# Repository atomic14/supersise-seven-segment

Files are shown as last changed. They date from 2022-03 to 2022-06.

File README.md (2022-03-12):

# Supersize Seven Segment Display

The code, schematics and PCB layout are offered here without any support. It's fun project but it's also a learning experience.

You can watch a full video of the completed project here: https://youtu.be/l18NYKRv0g0

Demo Video (https://www.youtube.com/watch?v=l18NYKRv0g0)

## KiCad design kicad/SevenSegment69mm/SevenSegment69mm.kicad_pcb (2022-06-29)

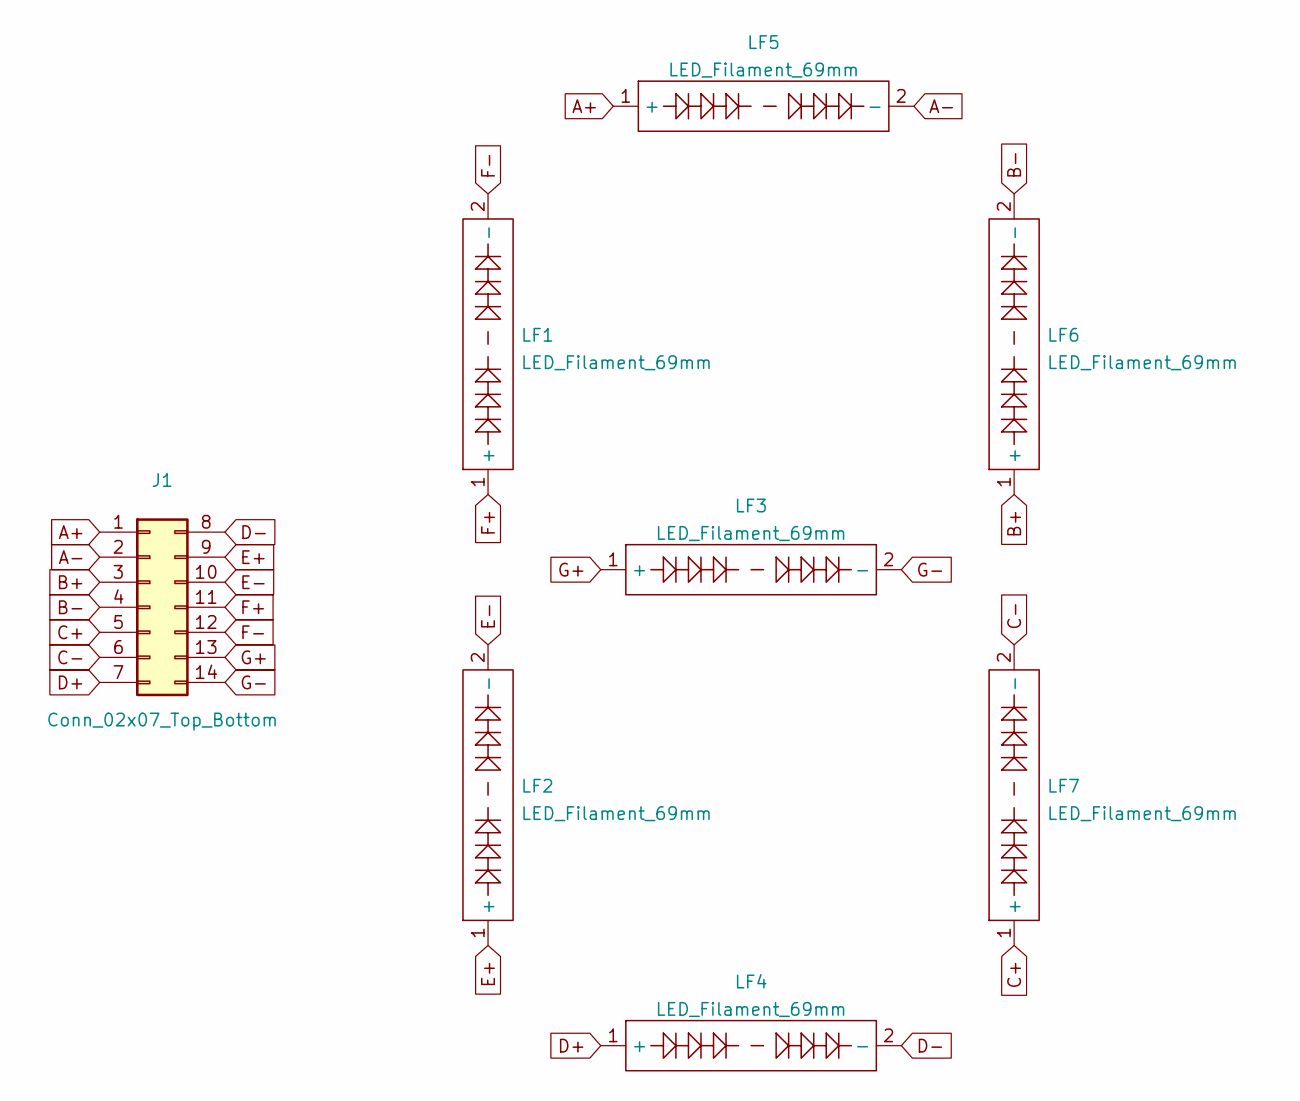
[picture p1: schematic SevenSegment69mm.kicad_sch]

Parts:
J1: Conn_02x07_Top_Bottom; PinHeader_2x07_P2.54mm_Horizontal
LF1, LF2, LF3, LF4, LF5, LF6, LF7: LED_Filament_69mm

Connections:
A+: J1.1, LF5.1 (+)
A-: J1.2, LF5.2 (-)
B+: J1.3, LF6.1 (+)
B-: J1.4, LF6.2 (-)
C+: J1.5, LF7.1 (+)
C-: J1.6, LF7.2 (-)
D+: J1.7, LF4.1 (+)
D-: J1.8, LF4.2 (-)
E+: J1.9, LF2.1 (+)
E-: J1.10, LF2.2 (-)
F+: J1.11, LF1.1 (+)
F-: J1.12, LF1.2 (-)
G+: J1.13, LF3.1 (+)
G-: J1.14, LF3.2 (-)

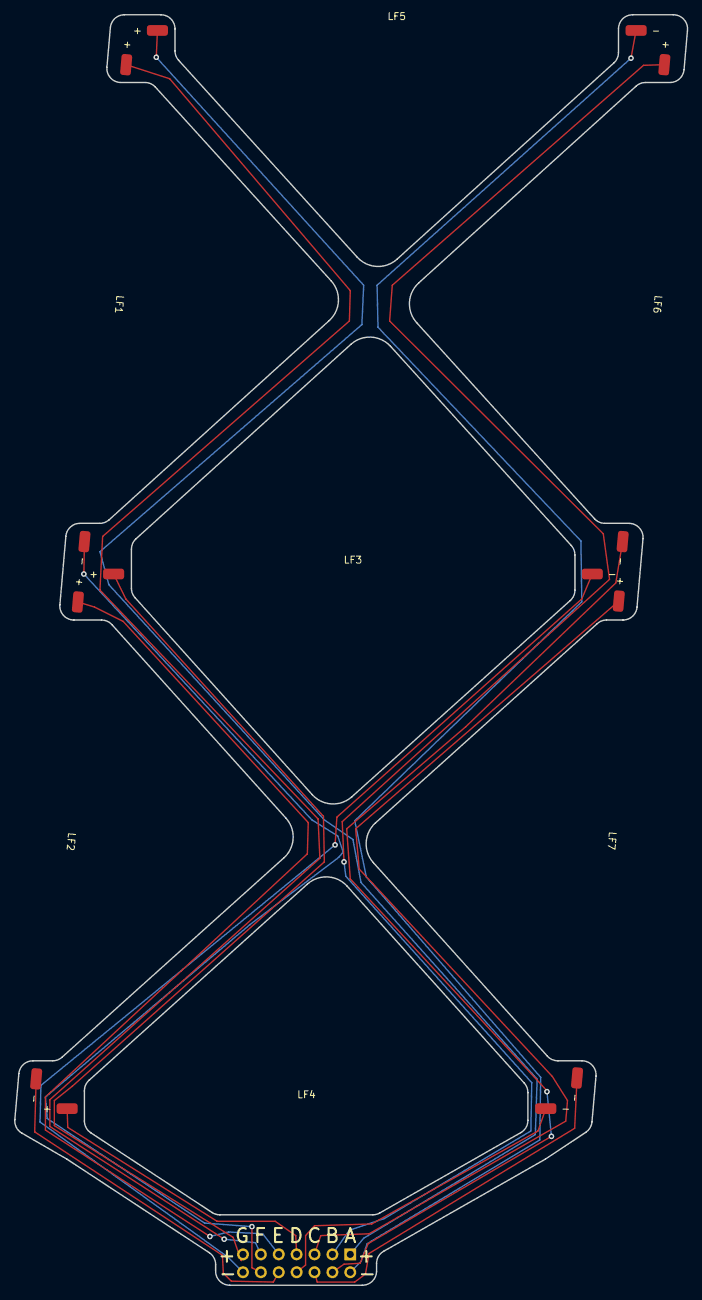
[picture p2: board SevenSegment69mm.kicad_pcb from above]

Board: 2 copper layers, 95.6 x 180.5 mm, 8 parts (0 on the bottom side), 14 nets.

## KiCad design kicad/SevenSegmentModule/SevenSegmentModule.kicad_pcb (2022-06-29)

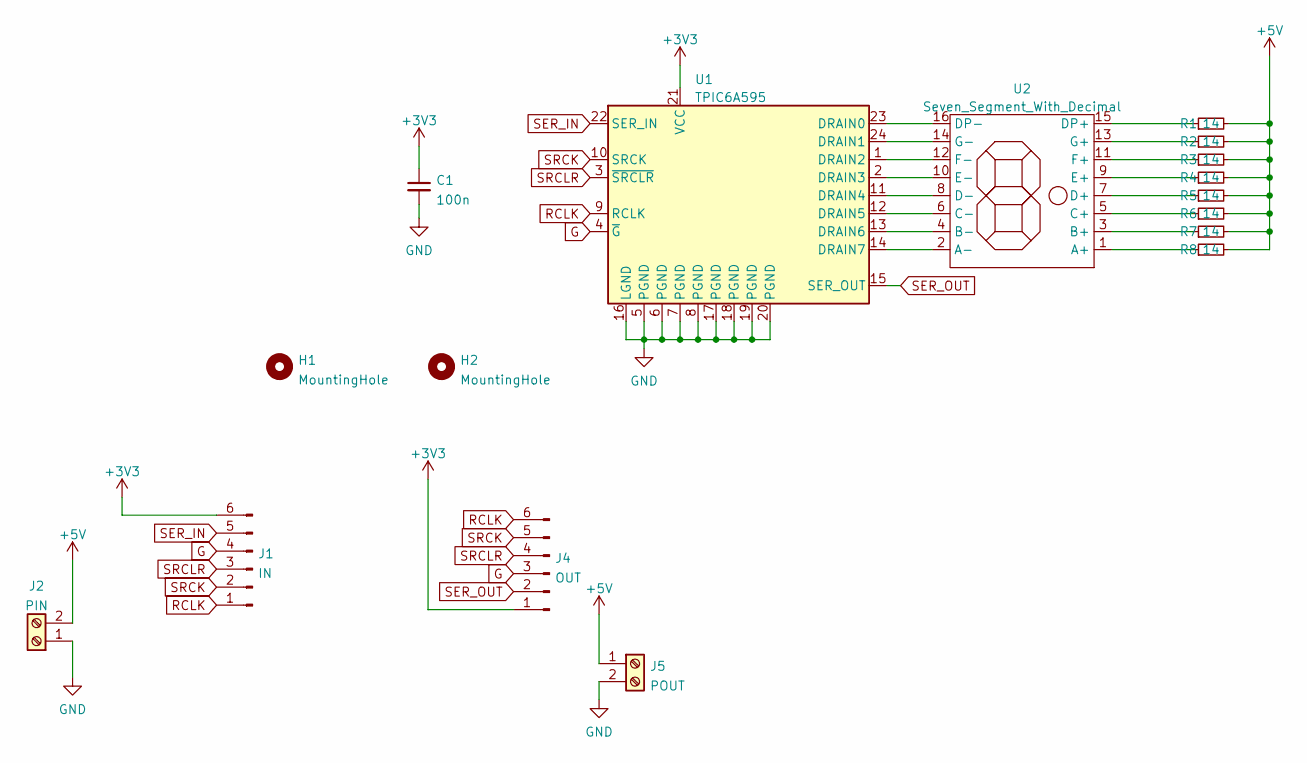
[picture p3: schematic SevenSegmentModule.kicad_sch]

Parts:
C1: 100n; C_0603_1608Metric
H1, H2: MountingHole; MountingHole_3.2mm_M3
J1: IN; PinHeader_1x06_P2.54mm_Horizontal
J2: PIN; TerminalBlock_Phoenix_MKDS-1,5-2-5.08_1x02_P5.08mm_Horizont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
J4: OUT; PinHeader_1x06_P2.54mm_Horizontal
J5: POUT; TerminalBlock_Phoenix_MKDS-1,5-2-5.08_1x02_P5.08mm_Horizont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
R1, R2, R3, R4, R5, R6, R7, R8: 14; R_0805_2012Metric
U1: TPIC6A595; SOIC-24W_7.5x15.4mm_P1.27mm
U2: Seven_Segment_With_Decimal; Segen_Segment_69mm_with_dp

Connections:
+3V3: C1.1, J1.6, J4.1, U1.21 (VCC)
+5V: J2.2, J5.1, R1.2, R2.2, R3.2, R4.2, R5.2, R6.2, R7.2, R8.2
G: J1.4, J4.3, U1.4 (~G)
GND: C1.2, J2.1, J5.2, U1.5 (PGND), U1.6 (PGND), U1.7 (PGND), U1.8 (PGND), U1.16 (LGND), U1.17 (PGND), U1.18 (PGND), U1.19 (PGND), U1.20 (PGND)
unnamed: R1.1, U2.15 (DP+)
unnamed: R2.1, U2.13 (G+)
unnamed: R3.1, U2.11 (F+)
unnamed: R4.1, U2.9 (E+)
unnamed: R5.1, U2.7 (D+)
unnamed: R6.1, U2.5 (C+)
unnamed: R7.1, U2.3 (B+)
unnamed: R8.1, U2.1 (A+)
unnamed: U1.14 (DRAIN7), U2.2 (A-)
unnamed: U1.13 (DRAIN6), U2.4 (B-)
unnamed: U1.12 (DRAIN5), U2.6 (C-)
unnamed: U1.11 (DRAIN4), U2.8 (D-)
unnamed: U1.2 (DRAIN3), U2.10 (E-)
unnamed: U1.1 (DRAIN2), U2.12 (F-)
unnamed: U1.24 (DRAIN1), U2.14 (G-)
unnamed: U1.23 (DRAIN0), U2.16 (DP-)
RCLK: J1.1, J4.6, U1.9 (RCLK)
SER_IN: J1.5, U1.22 (SER_IN)
SER_OUT: J4.2, U1.15 (SER_OUT)
SRCK: J1.2, J4.5, U1.10 (SRCK)
SRCLR: J1.3, J4.4, U1.3 (~SRCLR)

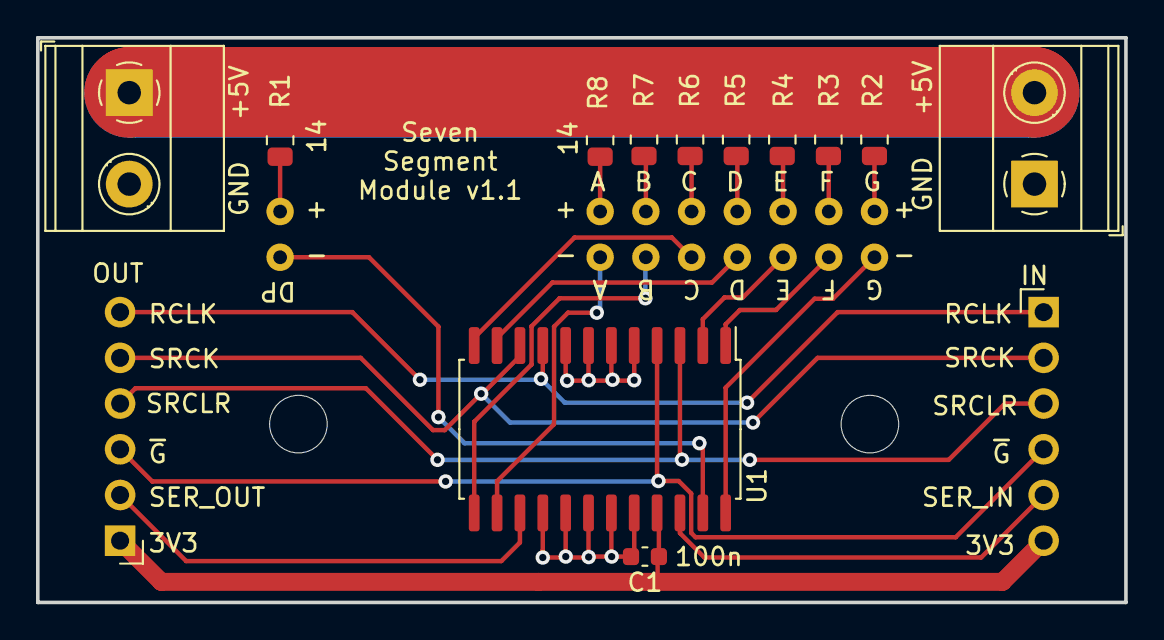
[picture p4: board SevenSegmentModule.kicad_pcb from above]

Board: 2 copper layers, 60.5 x 31.4 mm, 17 parts (0 on the bottom side), 25 nets.

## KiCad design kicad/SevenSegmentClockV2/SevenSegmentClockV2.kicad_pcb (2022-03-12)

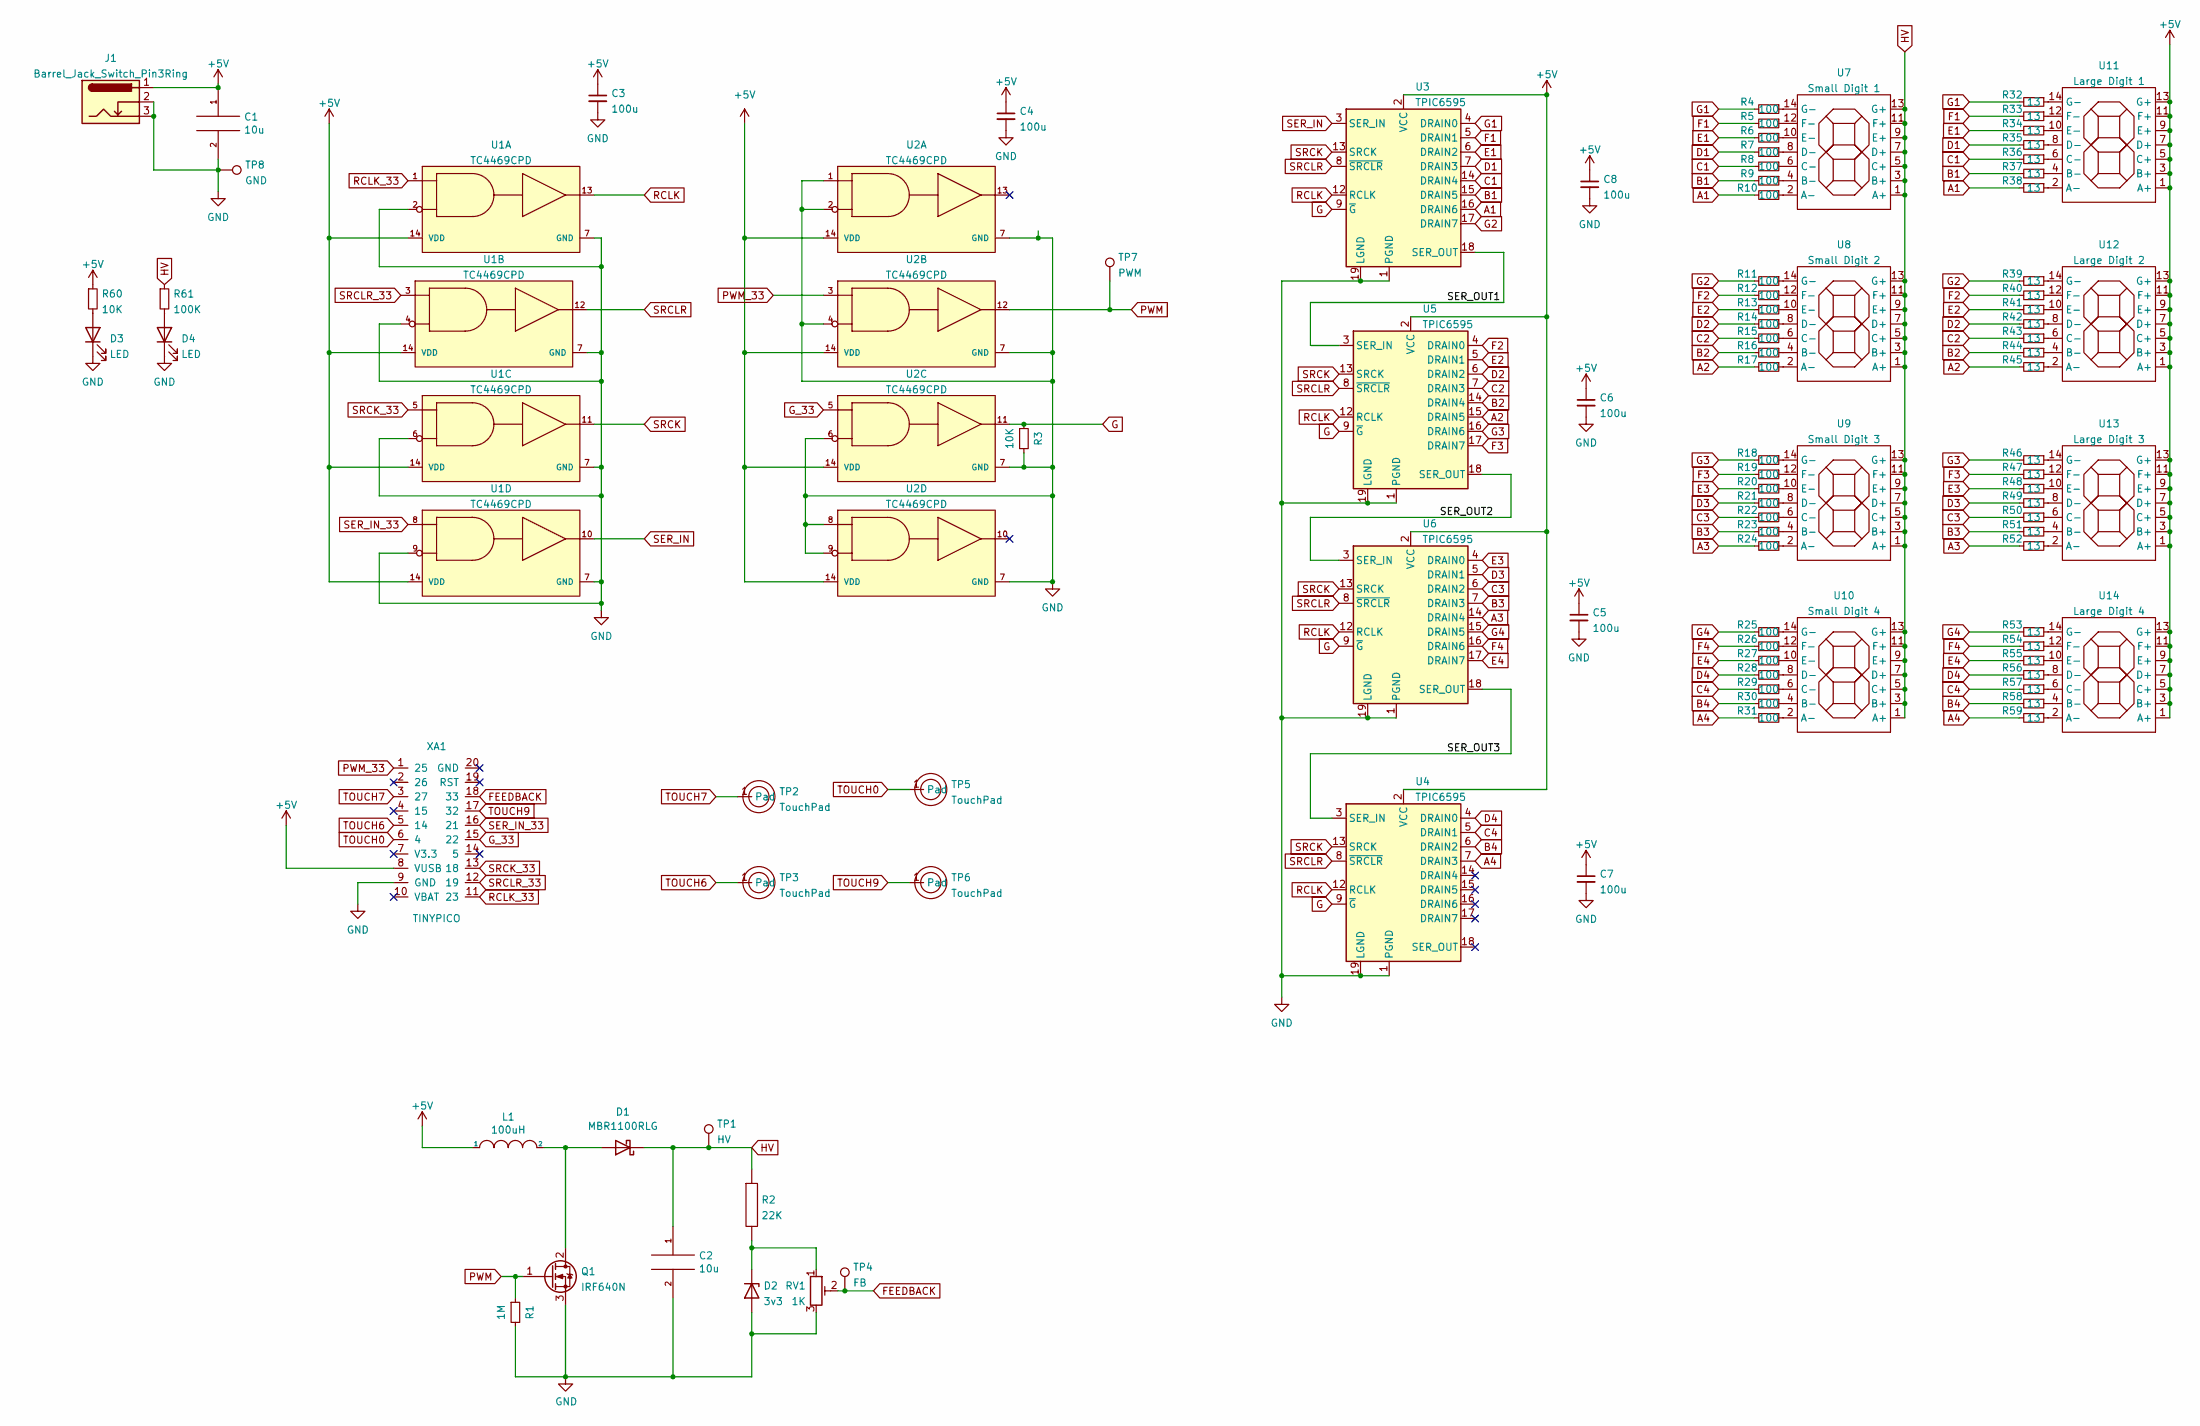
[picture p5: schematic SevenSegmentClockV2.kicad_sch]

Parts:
C1, C2: 10u; CP_Radial_D7.5mm_P2.50mm
C3, C4, C5, C6, C7, C8: 100u; C_0603_1608Metric_Pad1.08x0.95mm_HandSolder
D1: MBR1100RLG; D_DO-35_SOD27_P7.62mm_Horizontal
D2: 3v3; D_DO-35_SOD27_P7.62mm_Horizontal
D3, D4: LED; LED_0603_1608Metric_Pad1.05x0.95mm_HandSolder
J1: Barrel_Jack_Switch_Pin3Ring; BarrelJack_Horizontal
L1: 100uH; L_Radial_D7.5mm_P5.00mm_Fastron_07P
Q1: IRF640N; TO-220-3_Vertical
R1: 1M; R_0603_1608Metric_Pad0.98x0.95mm_HandSolder
R2: 22K; R_0603_1608Metric_Pad0.98x0.95mm_HandSolder
R3, R60: 10K; R_0603_1608Metric_Pad0.98x0.95mm_HandSolder
R4, R5, R6, R7, R8, R9, R10, R11, R12, R13, R14, R15, R16, R17, R18, R19, R20, R21, R22, R23, R24, R25, R26, R27, R28, R29, R30, R31: 100; R_Axial_DIN0207_L6.3mm_D2.5mm_P5.08mm_Vertical
R32, R33, R34, R35, R36, R37, R38, R39, R40, R41, R42, R43, R44, R45, R46, R47, R48, R49, R50, R51, R52, R53, R54, R55, R56, R57, R58, R59: 13; R_Axial_DIN0207_L6.3mm_D2.5mm_P5.08mm_Vertical
R61: 100K; R_0603_1608Metric_Pad0.98x0.95mm_HandSolder
RV1: 1K; Potentiometer_Bourns_3296W_Vertical
TP1: HV; TestPoint_Pad_4.0x4.0mm
TP2, TP3, TP5, TP6: TouchPad; TouchPad1
TP4: FB; TestPoint_Pad_4.0x4.0mm
TP7: PWM; TestPoint_Pad_4.0x4.0mm
TP8: GND; PinHeader_1x01_P2.54mm_Vertical
U1, U2: TC4469CPD; DIP-14_W7.62mm
U3, U4, U5, U6: TPIC6595; DIP-20_W7.62mm
U7: Small Digit 1; Segen_Segment_41mm
U8: Small Digit 2; Segen_Segment_41mm
U9: Small Digit 3; Segen_Segment_41mm
U10: Small Digit 4; Segen_Segment_41mm
U11: Large Digit 1; Segen_Segment_69mm
U12: Large Digit 2; Segen_Segment_69mm
U13: Large Digit 3; Segen_Segment_69mm
U14: Large Digit 4; Segen_Segment_69mm
XA1: TINYPICO

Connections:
+5V: C1.1, C3.1, C4.1, C5.1, C6.1, C7.1, C8.1, J1.1, L1.1, R60.1, U1.14 (VDD), U2.14 (VDD), U3.2 (VCC), U4.2 (VCC), U5.2 (VCC), U6.2 (VCC), U11.1 (A+), U11.3 (B+), U11.5 (C+), U11.7 (D+), U11.9 (E+), U11.11 (F+), U11.13 (G+), U12.1 (A+), U12.3 (B+), U12.5 (C+), U12.7 (D+), U12.9 (E+), U12.11 (F+), U12.13 (G+), U13.1 (A+), U13.3 (B+), U13.5 (C+), U13.7 (D+), U13.9 (E+), U13.11 (F+), U13.13 (G+), U14.1 (A+), U14.3 (B+), U14.5 (C+), U14.7 (D+), U14.9 (E+), U14.11 (F+), U14.13 (G+), XA1.8 (VUSB)
/SER_OUT1: U3.18 (SER_OUT), U5.3 (SER_IN)
/SER_OUT2: U5.18 (SER_OUT), U6.3 (SER_IN)
/SER_OUT3: U4.3 (SER_IN), U6.18 (SER_OUT)
A1: R10.2, R38.2, U3.16 (DRAIN6)
A2: R17.2, R45.2, U5.15 (DRAIN5)
A3: R24.2, R52.2, U6.14 (DRAIN4)
A4: R31.2, R59.2, U4.7 (DRAIN3)
B1: R9.2, R37.2, U3.15 (DRAIN5)
B2: R16.2, R44.2, U5.14 (DRAIN4)
B3: R23.2, R51.2, U6.7 (DRAIN3)
B4: R30.2, R58.2, U4.6 (DRAIN2)
C1: R8.2, R36.2, U3.14 (DRAIN4)
C2: R15.2, R43.2, U5.7 (DRAIN3)
C3: R22.2, R50.2, U6.6 (DRAIN2)
C4: R29.2, R57.2, U4.5 (DRAIN1)
D1: R7.2, R35.2, U3.7 (DRAIN3)
D2: R14.2, R42.2, U5.6 (DRAIN2)
D3: R21.2, R49.2, U6.5 (DRAIN1)
D4: R28.2, R56.2, U4.4 (DRAIN0)
E1: R6.2, R34.2, U3.6 (DRAIN2)
E2: R13.2, R41.2, U5.5 (DRAIN1)
E3: R20.2, R48.2, U6.4 (DRAIN0)
E4: R27.2, R55.2, U6.17 (DRAIN7)
F1: R5.2, R33.2, U3.5 (DRAIN1)
F2: R12.2, R40.2, U5.4 (DRAIN0)
F3: R19.2, R47.2, U5.17 (DRAIN7)
F4: R26.2, R54.2, U6.16 (DRAIN6)
FEEDBACK: RV1.2, TP4.1, XA1.18 (33)
G: R3.1, U2.11 (3Y), U3.9 (~G), U4.9 (~G), U5.9 (~G), U6.9 (~G)
G1: R4.2, R32.2, U3.4 (DRAIN0)
G2: R11.2, R39.2, U3.17 (DRAIN7)
G3: R18.2, R46.2, U5.16 (DRAIN6)
G4: R25.2, R53.2, U6.15 (DRAIN5)
GND: C1.2, C2.2, C3.2, C4.2, C5.2, C6.2, C7.2, C8.2, D2.2 (A), D3.1 (K), D4.1 (K), J1.2, J1.3, Q1.3 (S), R1.2, R3.2, RV1.3, TP8.1, U1.2 (1B), U1.4 (2B), U1.6 (3B), U1.7 (GND), U1.9 (4B), U2.1 (1A), U2.2 (1B), U2.4 (2B), U2.6 (3B), U2.7 (GND), U2.8 (4A), U2.9 (4B), U3.1 (PGND), U3.10 (PGND), U3.11 (PGND), U3.19 (LGND), U3.20 (PGND), U4.1 (PGND), U4.10 (PGND), U4.11 (PGND), U4.19 (LGND), U4.20 (PGND), U5.1 (PGND), U5.10 (PGND), U5.11 (PGND), U5.19 (LGND), U5.20 (PGND), U6.1 (PGND), U6.10 (PGND), U6.11 (PGND), U6.19 (LGND), U6.20 (PGND), XA1.9 (GND)
G_33: U2.5 (3A), XA1.15 (22)
HV: C2.1, D1.1 (K), R2.1, R61.1, TP1.1, U7.1 (A+), U7.3 (B+), U7.5 (C+), U7.7 (D+), U7.9 (E+), U7.11 (F+), U7.13 (G+), U8.1 (A+), U8.3 (B+), U8.5 (C+), U8.7 (D+), U8.9 (E+), U8.11 (F+), U8.13 (G+), U9.1 (A+), U9.3 (B+), U9.5 (C+), U9.7 (D+), U9.9 (E+), U9.11 (F+), U9.13 (G+), U10.1 (A+), U10.3 (B+), U10.5 (C+), U10.7 (D+), U10.9 (E+), U10.11 (F+), U10.13 (G+)
unnamed: D1.2 (A), L1.2, Q1.2 (D)
unnamed: D2.1 (K), R2.2, RV1.1
unnamed: D3.2 (A), R60.2
unnamed: D4.2 (A), R61.2
unnamed: R4.1, U7.14 (G-)
unnamed: R5.1, U7.12 (F-)
unnamed: R6.1, U7.10 (E-)
unnamed: R7.1, U7.8 (D-)
unnamed: R8.1, U7.6 (C-)
unnamed: R9.1, U7.4 (B-)
unnamed: R10.1, U7.2 (A-)
unnamed: R11.1, U8.14 (G-)
unnamed: R12.1, U8.12 (F-)
unnamed: R13.1, U8.10 (E-)
unnamed: R14.1, U8.8 (D-)
unnamed: R15.1, U8.6 (C-)
unnamed: R16.1, U8.4 (B-)
unnamed: R17.1, U8.2 (A-)
unnamed: R18.1, U9.14 (G-)
unnamed: R19.1, U9.12 (F-)
unnamed: R20.1, U9.10 (E-)
unnamed: R21.1, U9.8 (D-)
unnamed: R22.1, U9.6 (C-)
unnamed: R23.1, U9.4 (B-)
unnamed: R24.1, U9.2 (A-)
unnamed: R25.1, U10.14 (G-)
unnamed: R26.1, U10.12 (F-)
unnamed: R27.1, U10.10 (E-)
unnamed: R28.1, U10.8 (D-)
unnamed: R29.1, U10.6 (C-)
unnamed: R30.1, U10.4 (B-)
unnamed: R31.1, U10.2 (A-)
unnamed: R32.1, U11.14 (G-)
unnamed: R33.1, U11.12 (F-)
unnamed: R34.1, U11.10 (E-)
unnamed: R35.1, U11.8 (D-)
unnamed: R36.1, U11.6 (C-)
unnamed: R37.1, U11.4 (B-)
unnamed: R38.1, U11.2 (A-)
unnamed: R39.1, U12.14 (G-)
unnamed: R40.1, U12.12 (F-)
unnamed: R41.1, U12.10 (E-)
unnamed: R42.1, U12.8 (D-)
unnamed: R43.1, U12.6 (C-)
unnamed: R44.1, U12.4 (B-)
unnamed: R45.1, U12.2 (A-)
unnamed: R46.1, U13.14 (G-)
unnamed: R47.1, U13.12 (F-)
unnamed: R48.1, U13.10 (E-)
unnamed: R49.1, U13.8 (D-)
unnamed: R50.1, U13.6 (C-)
unnamed: R51.1, U13.4 (B-)
unnamed: R52.1, U13.2 (A-)
unnamed: R53.1, U14.14 (G-)
unnamed: R54.1, U14.12 (F-)
unnamed: R55.1, U14.10 (E-)
unnamed: R56.1, U14.8 (D-)
unnamed: R57.1, U14.6 (C-)
unnamed: R58.1, U14.4 (B-)
unnamed: R59.1, U14.2 (A-)
PWM: Q1.1 (G), R1.1, TP7.1, U2.12 (2Y)
PWM_33: U2.3 (2A), XA1.1 (25)
RCLK: U1.13 (1Y), U3.12 (RCLK), U4.12 (RCLK), U5.12 (RCLK), U6.12 (RCLK)
RCLK_33: U1.1 (1A), XA1.11 (23)
SER_IN: U1.10 (4Y), U3.3 (SER_IN)
SER_IN_33: U1.8 (4A), XA1.16 (21)
SRCK: U1.11 (3Y), U3.13 (SRCK), U4.13 (SRCK), U5.13 (SRCK), U6.13 (SRCK)
SRCK_33: U1.5 (3A), XA1.13 (18)
SRCLR: U1.12 (2Y), U3.8 (~SRCLR), U4.8 (~SRCLR), U5.8 (~SRCLR), U6.8 (~SRCLR)
SRCLR_33: U1.3 (2A), XA1.12 (19)
TOUCH0: TP5.1 (Pad), XA1.6 (4)
TOUCH6: TP3.1 (Pad), XA1.5 (14)
TOUCH7: TP2.1 (Pad), XA1.3 (27)
TOUCH9: TP6.1 (Pad), XA1.17 (32)

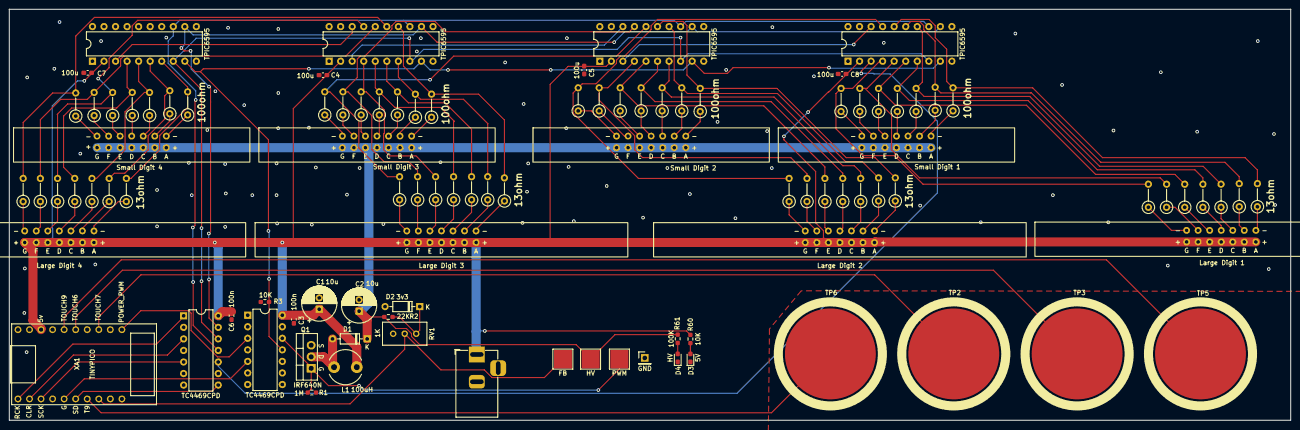
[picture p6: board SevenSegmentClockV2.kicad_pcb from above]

Board: 2 copper layers, 281.9 x 90.4 mm, 100 parts (0 on the bottom side), 111 nets.

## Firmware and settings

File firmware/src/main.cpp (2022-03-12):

#include <Arduino.h>
#include <WiFi.h>
#include "BoostSupply.h"
#include "Digits.h"
#include "TimeWrapper.h"
#include "StopWatch.h"
#include "StateMachine.h"
#include <driver/timer.h>
#include <driver/gpio.h>

const adc1_channel_t BOOST_FEEDBACK_PIN = ADC1_CHANNEL_5;
const gpio_num_t BOOST_PWM_PIN = GPIO_NUM_25;
const gpio_num_t SERIAL_OUT_PIN = GPIO_NUM_21;
const gpio_num_t SERIAL_CLOCK_PIN = GPIO_NUM_18;
const gpio_num_t SERIAL_LATCH_PIN = GPIO_NUM_23;
const gpio_num_t SERIAL_CLR_PIN = GPIO_NUM_19;
const gpio_num_t SERIAL_ENABLE_PIN = GPIO_NUM_22;

BoostSupply *boost_supply;
Digits *digits;
TimeWrapper *time_wrapper;
StopWatch *stop_watch;
StateMachine *state_machine;
hw_timer_t *timer = NULL;

int timer_count = 0;
void timer_callback()
{
  // monitor and apply any adjustments to the boost supply
  boost_supply->service();
  timer_count++;
}

void touch_button1_isr()
{
  state_machine->proccess_event(Event::BUTTON1_TOUCH);
}

void touch_button2_isr()
{
  state_machine->proccess_event(Event::START_STOP_TOUCH);
}

void touch_button3_isr()
{
  state_machine->proccess_event(Event::RESET_TOUCH);
}

void touch_button4_isr()
{
  state_machine->proccess_event(Event::BUTTON4_TOUCH);
}

void setup()
{
  Serial.begin(115200);
  // connect to wifi
  Serial.println("Connecting to wifi...");
  WiFi.begin("CMGResearch_old", "02087552867");
  while (WiFi.status() != WL_CONNECTED)
  {
    delay(500);
    Serial.print(".");
  }
  // start up the boost power supply
  boost_supply = new BoostSupply(BOOST_PWM_PIN, BOOST_FEEDBACK_PIN);
  // create our 4 seven segment digits
  digits = new Digits(4);
  // create the stopwatch
  stop_watch = new StopWatch();
  // kick off time
  time_wrapper = new TimeWrapper();
  // this is the state machine that controls everything
  state_machine = new StateMachine(time_wrapper, stop_watch);
  // start up a timer to service the boost supply and write out the segments
  timer = timerBegin(0, 80, true); // this will run a timer with a 1MHz clock (80MHz/80 = 1MHz)
  timerAttachInterrupt(timer, &timer_callback, true);
  timerAlarmWrite(timer, 500, true); // wake up everytime we hit 100 ticks (10KHz)
  timerAlarmEnable(timer);
  // setup the shift registeros
  pinMode(SERIAL_OUT_PIN, OUTPUT);
  pinMode(SERIAL_CLOCK_PIN, OUTPUT);
  pinMode(SERIAL_LATCH_PIN, OUTPUT);
  pinMode(SERIAL_CLR_PIN, OUTPUT);
  pinMode(SERIAL_ENABLE_PIN, OUTPUT);
  // clear the shift register
  digitalWrite(SERIAL_CLR_PIN, LOW);
  digitalWrite(SERIAL_CLR_PIN, HIGH);
  // copy to the output registers
  digitalWrite(SERIAL_LATCH_PIN, HIGH);
  digitalWrite(SERIAL_LATCH_PIN, LOW);
  // and enable the output
  digitalWrite(SERIAL_ENABLE_PIN, LOW);
  // digitalWrite(SERIAL_ENABLE_PIN, HIGH);

  // set up the touch buttons
  touchAttachInterrupt(T9, touch_button1_isr, 20);
  touchAttachInterrupt(T7, touch_button2_isr, 40);
  touchAttachInterrupt(T6, touch_button3_isr, 40);
  touchAttachInterrupt(T0, touch_button4_isr, 20);
}

int count = 0;
int wait = 0;
void loop()
{
  // interesting stats
  // Serial.printf("duty:%f,v:%f,t:55\n", 100.0f * boost_supply->get_duty() / 1024000.0f, boost_supply->get_feedback_voltage() / 10.0);
  // update the current time
  if (!time_wrapper->update())
  {
    Serial.printf("time update failed\n");
  }
  // update the digits depending on our current state
  int get_display_digits = state_machine->get_display_digits();
  // int get_display_digits = count;
  Serial.printf("digits:%d\n", get_display_digits);
  for (int d = 3; d >= 0; d--)
  {
    digits->set_digit(d, get_display_digits % 10);
    get_display_digits /= 10;
  }
  // clock out all the segments to the shift registers
  for (int digit = 0; digit < 4; digit++)
  {
    for (int segment = 0; segment < 7; segment++)
    {
      // digitalWrite(SERIAL_OUT_PIN, (segment + digit * 7) < count);
      // digitalWrite(SERIAL_OUT_PIN, HIGH);
      // // set the value
      digitalWrite(SERIAL_OUT_PIN, digits->get_digit_segment(digit, segment));
      // // pulse the clock pin
      digitalWrite(SERIAL_CLOCK_PIN, HIGH);
      digitalWrite(SERIAL_CLOCK_PIN, LOW);
    }
  }
  // wait++;
  // if (wait == 300)
  // {
  //   wait = 0;
  //   count++;
  //   if (count > 4 * 7)
  //   {
  //     count = 0;
  //   }
  // }
  // // push the segment values to the output registers
  digitalWrite(SERIAL_LATCH_PIN, HIGH);
  digitalWrite(SERIAL_LATCH_PIN, LOW);
  // Serial.printf("%d\n", timer_count);
  delay(100);
  // Serial.printf("State:%d\n", state_machine->get_state());

  // Serial.printf("T9:%d,T7:%d,T6:%d,T0:%d\n", touchRead(T9), touchRead(T7), touchRead(T6), touchRead(T0));
}

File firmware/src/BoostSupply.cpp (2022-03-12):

#include "BoostSupply.h"
#include <driver/ledc.h>
#include <Arduino.h>

static const int MAX_DUTY = ((1000 * 70 * 1024) / 100);
static const int MIN_DUTY = ((1000 * 5 * 1024) / 100);
static const int MID_DUTY = ((1000 * 50 * 1024) / 100);

BoostSupply::BoostSupply(gpio_num_t pwm_pin, adc1_channel_t feedback_pin)
{
    m_feedback_pin = feedback_pin;
    // configure the ADC
    adc1_config_width(ADC_WIDTH_BIT_12);
    adc1_config_channel_atten(feedback_pin, ADC_ATTEN_DB_0);

    // get the characteristics of ADC1
    esp_adc_cal_value_t val_type = esp_adc_cal_characterize(
        ADC_UNIT_1,
        ADC_ATTEN_DB_0,
        ADC_WIDTH_BIT_12,
        1100,
        &adc_chars);
    Serial.printf("ADC calibration type for unit %d: %d\n", ADC_UNIT_1, val_type);
    if (val_type == ESP_ADC_CAL_VAL_EFUSE_TP)
    {
        Serial.println("Characterized using Two Point Value");
    }
    else if (val_type == ESP_ADC_CAL_VAL_EFUSE_VREF)
    {
        Serial.println("Characterized using eFuse Vref");
    }
    else
    {
        Serial.println("Characterized using Default Vref");
    }
    // setup the PWM output
    ledc_timer_config_t ledc_timer = {};
    ledc_timer.speed_mode = LEDC_HIGH_SPEED_MODE;
    ledc_timer.duty_resolution = LEDC_TIMER_10_BIT;
    ledc_timer.timer_num = LEDC_TIMER_0;
    ledc_timer.freq_hz = 20000;

    ledc_timer_config(&ledc_timer);

    // configure the duty cycle and gpio number
    ledc_channel_config_t ledc_channel = {0};
    ledc_channel.channel = LEDC_CHANNEL_0;
    ledc_channel.duty = MIN_DUTY / 1000;
    ledc_channel.gpio_num = pwm_pin;
    ledc_channel.speed_mode = LEDC_HIGH_SPEED_MODE;
    ledc_channel.timer_sel = LEDC_TIMER_0;

    ledc_channel_config(&ledc_channel);

    for (int i = 0; i < NUMBER_OF_SAMPLES; i++)
    {
        samples[i] = 0;
    }
    duty = MIN_DUTY;
    feedback_voltage = 0;
    sample_index = 0;
}

void BoostSupply::service()
{
    // calculate the median value of the feedback pin over a number of samples
    // samples[sample_index] = adc1_get_raw(m_feedback_pin);
    // sample_index++;
    // if (sample_index == NUMBER_OF_SAMPLES)
    // {
    //     sample_index = 0;
    // }
    // uint32_t ave = 0;
    // for (int i = 0; i < NUMBER_OF_SAMPLES; i++)
    // {
    //     ave += samples[i];
    //     ave += adc1_get_raw(m_feedback_pin);
    // }
    // uint32_t value_sense = ave / NUMBER_OF_SAMPLES;
    uint32_t values[NUMBER_OF_SAMPLES];
    for (int i = 0; i < NUMBER_OF_SAMPLES; i++)
    {
        values[i] = adc1_get_raw(m_feedback_pin);
    }
    std::sort(values, values + NUMBER_OF_SAMPLES);
    uint32_t value_sense = (values[NUMBER_OF_SAMPLES / 2] + values[NUMBER_OF_SAMPLES / 2 - 1]) / 2;
    feedback_voltage = esp_adc_cal_raw_to_voltage(value_sense, &adc_chars);

    int voltage_diff = 600 - feedback_voltage;
    duty += 100 * voltage_diff;
    duty = std::max(std::min(duty, MAX_DUTY), MIN_DUTY);

    ledc_set_duty(LEDC_HIGH_SPEED_MODE, LEDC_CHANNEL_0, duty / 1000);
    ledc_update_duty(LEDC_HIGH_SPEED_MODE, LEDC_CHANNEL_0);
}

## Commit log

2022-03-03 Initial cut of digi driving
2022-03-07 power supply working
2022-03-12 Adds kicad files
    [SevenSegmentClockV2.kicad_pcb, SevenSegmentClockV2.kicad_sch]
2022-03-28 WIP - seven segment modules and decimal place
    [DecimalPlace-B_Cu.gbl, DecimalPlace-B_Mask.gbs, DecimalPlace-B_Paste.gbp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]
2022-06-29 Add modular PCBs and cleanup backups
    [DecimalPlace-B_Cu.gbl, DecimalPlace-B_Mask.gbs, DecimalPlace-B_Paste.gbp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]
2022-06-29 Adds the digit
    [SevenSegment69mm.kicad_pcb, SevenSegment69mm.kicad_sch]
